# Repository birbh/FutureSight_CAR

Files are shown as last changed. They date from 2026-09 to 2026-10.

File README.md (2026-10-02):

# FutureSight_CAR:
FutureSight is an automotive dashcam built from scratch from Milk-V Duo S. It features hardware accelerated 1680p continuous loop recording with an 12c G-sensor for auto crash detection. Also I have prepared a custom 12 volt to 5 volt power converting board to handle the non sturdy vehicle(car) power.

## What makes it unique??
Unlike the commercial dashcams that lock footage behind their own apps. This project gives a person complete access and ownership of hardware and software stack. It runs a raw python on RISC-V Linux env. The hardware stack si built for extreme durability, utilizing a TPS54360DDA bulk converter and a 5.5V 4.0F supercapacitor for safe shutdown and giving time to save files before car switches off. Also it is designed to manage heat efficiently by using the large heat sync in the back panel and go-pro style mounting hinge so that it can be rotated to any angle. 

## Why i made it?
Recently my father's car got into an accident and he paid the damaged repairing cost although it wasn't his fault. So from that day i thought it would be cool if we get a dashcam(a good one). But after seeing the dashcams online the good ones were so expensive. So i thought why not make my own dashcam in home. Also i thought driving a car in those busy and chaotic roads of Kathmandu would be easier and feel confident because everything you and other person do is fully recorded and also helps us to be in discipline cause we think that this all is being recorded and we are bound to laws. 

## How to use it?
1. Mount+wire:
  Attach the dashcam module(assembled) to your car windshield using gopro compatible mount provided in 3d files of repo. Then wire 2 pin screw terminal on pcb directly to 12V power source in your car sing a cigarette lighter adapter for car.

2. Starting dashcam:
  Turn on your car. Then the system boots automatically and providing power to Milk-v-duo S. Then a background service immediately starts recording a video in 3 min. chunks.

3. Storage management:
  When the microsd card fills up, the software automatically deletes oldest normal driving footage.

4. Smart impact protection:
  If the MPU-6050 accelerometer chip detects a sudden G-force spike(triggered by eg:: hard braking, collision, car slipping etc.) , then the current video is instantly locked into `/events/` folder in sd card where it can't be overwritten. Otherwise if you press a button in the back of the dashcam it will be auto saved to `/events/` folder. Other normal recordings are saved to `/normal` folder.

## Assembly Instructions:
### 3d print enclosure:
All te 3d CAD files are provided in CAD folder of this repo. And especially 3d printable parts can be found on `/CAD/3d print/` folder in this repo. Use a high tempetrature resistant filament profile like ABS or ASA. Don't use PLA or PETG as they are not so resistant to heat and can melt on car interior temp. as it easily reaches about 70-80 °C in summer season. Also all the mounts have been pre defined in the CAD so there is no need to worry for screw fitting. 

### PCB and soldering:
Fabricate the custom matte black Kicad Pcb. Solder the SMD components first paying special attention to all components. Also before pcb printing check the 12v-5v power lines are of 1-1.5 mm width. Then solder the all the required parts to their respective footprints and places. Also snap the Milk-v-Duo S to its respective place J1 And J2 same as shown in 3d CAD model. Please ensure all the pins are arranged with the pcb otherwise it will not function. Also note that the upper black thing is completely optional because they are just pin headers that are add in 3d model. 

### Mounting:
I have provided each and every screw slots in the 3d model so that each component easily fits into the enclosure. Also dont forget to connect the camera to the milk-v duo s connector cause without camera the system is nothing. To mount camera you must take the lid side and mount the screws into it s that camera stays fit in it. 

### Flashing firmware:
Flash the official MIlk-V OS image into your SDcard. Then connect them via onboard micro sd adapter and install the required dependencies(ffmpeg,python3,py3-smbus2). Create `/mnt/sdcard/dashcam/normal/` and `/mnt/sdcard/dashcam/events/` folder/directories inside the sd card. Drop the firmware files in the root folder and enable it as a startup service. 

### Getting the data:
For now you can extract your dashcam videos by unplugging the Sd-card from the dashcam and plugging it in the sd card reader in pc,mobile or any other mountable device. And also you can directly connect your milk v type c port into your pc and access your data. But in future i plan to make a native app for the dashcam and use the inbuilt wifi antenna thing to sync the data. Also i plan to make the app fully run locally in users’ devices, protecting the privacy of the user.  

## Milk-V Duo S setup(in detail):
Once your Pcb is soldered and milk-v duo-s is mounted, follow these steps to configure dashcam:::

1. Flash the OS:
  - Download the official Milk-V Duo S Linux image from milk v [Github repo](https://github.com/milkv-duo/duo-buildroot-sdk-v2/releases)
  - then flash the image to a micros card using tools like Rufus or balenaEtcher or any other image flashing software.
  - insert the micro sd card into duo s and power it using the USB-C port(note: don't apply the car 12V power yet.)

2. Install the required drivers:
  i. For Windows users:
    Windows often fails to recognize the board automatically. You need to tell it to treat the USB connection as a network card.
    - Open Device Manager: Look under Other devices for an unknown device (often labeled Serial or RNDIS).
    - Update Driver: Right-click it, select Update driver, and choose Browse my computer for drivers.
    - Select from List: Click Let me pick from a list of available drivers on my computer.
    - Choose Network Adapters: Select Network adapters from the list, choose Microsoft as the manufacturer, and select Remote NDIS Compatible Device (or USB RNDIS Adapter).
    - Finish: Click Next and ignore any warning prompts.
    
  ii. For macos/Linux users:
    Linux and Mac usually recognize the RNDIS interface automatically, but you need to check if the network interface is active.
    - Open Terminal: Run ip a (Linux) or ifconfig (Mac).
    - Look for a new interface: You should see a new network interface (usually named something like usb0 or enX).
    
3. Setup SSH into the board:
  - Connect the Milk-V Duo S into your computer after installing required drivers.It will mount as a virtual network adapter(RNDIS).
  - Open your terminal and SSH into your default IP adress `192.168.42.1`.
  - ```bash
    ssh root@192.168.42.1
    ```
  - the default password is typically `milkv`

4. Install dependencies:
  Depending on specific os image you flashed, use the system package manager to install reqd video and python packages:
  - ```bash
    apt-get update
    sudo apt install ffmpeg
    sudo apt install python3 python3-pip
    pip3 install smbus2
    ```
5. Create the required storage directories:
  - ```bash
    mkdir -p/mnt/sdcard/dashcam/normal/
    mkdir -p/mnt/sdcard/dashcam/events/
    
6. Transfer the python script(firmware):
  From your computer use SCP(secure copy) protocol to transfer your finalized firmware firmware.py script into root folder of Milk-V Duo S:
  ```bash
scp firmware.py root@192.168.42.1:/root/
```

7. Create auto-start service when boot:
   The dashcam must boot on its own when car turns on. So use systemd to make script aut run in the bg:
   - Create the service file:
   ```bash
   vi /etc/systemd/system/dashcam.service
   ```
   - Paste the exact configuration into the file:
   ```bash
      [Unit]
      Description=Dashcam Auto recors svc
      After=systemd-modules-load.service
      
      [Service]
      Type=simple
      ExecStart=/usr/bin/python3 /root/firmware.py
      Restart=always
      RestartSec=3
      
      [Install]
      WantedBy=multi-user.target
   ```
  - Save the file and exit.

8. Enable and test:
  - Enable the service so it starts automatically on every boot.Also start manually to test it now:
    ```bash
    systemctl enable dashcam.service
    systemctl start dashcam.service
    ```
  - Verify that the camera is recording and G-sensor is polling by checking the status:
    ```bash
    systemctl status dashcam.service
    ```
  - Now at this point the usb-c cable can be disconnected and your dashcam is ready to be mounted inside the car Cigarette Lighter 12V port.... YAYYYYYY!!! les goooooooo!! 

## Future changes:
I have kept the ipex connector cable with wifi+bluetooth antenna in the pcb,BOM and CAD but that is completely optional for now as the app and the wifi setup hasnt been added in the firmware yet. In future it will be added. Also the app for the dashcam isnt functional yet and will be updated in future.

## Assets:
### CAD screenshots:
Screenshot 2026-10-02 at 6 51 13 PM
Screenshot 2026-10-02 at 6 51 52 PM
Screenshot 2026-10-02 at 6 51 38 PM
Screenshot 2026-10-02 at 6 53 03 PM
Screenshot 2026-10-02 at 6 53 45 PM

### CAD link:
[Fusion Link](https://a360.co/47AANnS)

### PCB screenshots:
Screenshot 2026-10-02 at 6 42 15 PM
Screenshot 2026-10-02 at 6 46 31 PM
Screenshot 2026-10-02 at 6 46 49 PM
Screenshot 2026-10-02 at 11 10 06 PM
Screenshot 2026-10-02 at 11 11 20 PM

### Schematic:
1. Power Control:
Screenshot 2026-10-02 at 6 48 12 PM

2. Safe shut
Screenshot 2026-10-02 at 6 49 03 PM

3. Duos_interface:
Screenshot 2026-10-02 at 6 50 06 PM

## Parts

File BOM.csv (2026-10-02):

Designator | Footprint | Quantity | Value | Component | Price | Link
C_BOOT1 | 0603 | 1 | 0.1µF | capacitor_x7r (16v or 25v) | $.11 | https://shorturl.at/1SRxo
C_COMP1 | 0603 | 1 | 3.3nF | capacitor_x7r (50v) | $.12 | https://h1.nu/1z8wH
C_IN1 | 1206 | 1 | 10µF | capacitor_x7r(50v) | $.71 | https://shorturl.at/bqJFe
C_IN2 | CP_Elec_6.3x5.8 | 1 | 47µF | capacitor_aluminium-elec(50v) | $.84 | https://h1.nu/1z8y9
C_MPU1 | 0603 | 1 | 0.1µF 10V | capacitor(10v) | $.85 | https://h1.nu/1z8z7
C_OUT1, C_OUT2 | 1206 | 2 | 22µF | capacitor_x7r(10v or 16v) | $2.25 | https://h1.nu/1z8CW
C_SUPER1 | CP_Radial_D13.0mm_P5.00mm | 1 | 5.5V 4.0F | Supercapacitor | $3.28 | https://shorturl.at/uentd
D1 | DIOM4336X265N | 1 | SMBJ24A | Unidirectional TVS Diode | $.63 | https://h1.nu/1zcSl
D2 | D_SMA_Handsoldering | 1 | 40V 3A | Schottky diode_sma | $.88 | https://h1.nu/1F28f
D_BACKUP1, D_MAIN1 | D_SMC_Handsoldering | 2 | 40V 3A | Schottky diode_smc | $3.04 | https://h1.nu/1zcYR
D_STAT1 | 0603 | 1 | LED_Small | Led-red | $.21 | https://h1.nu/1F1Za
F1 | 1812 | 1 | Polyfuse | 1812L150/24MR | $.82 | https://h1.nu/1zcVP
J1, J2 | PinSocket_2x13_P2.54mm_Vertical | 1 | Conn_02x13_Odd_Even | Milk-V-Duo-S dev board | $30.25 | https://h1.nu/1zcQ0
J3 | TerminalBlock_Phoenix_MKDS-1,5-2-5.08_1x02_P5.08mm_Horizontal | 1 | Conn_01x02 | Header to car cigratte connector | $1.16 | https://h1.nu/1F23B
L1 | L_Bourns-SRN8040_8x8.15mm | 1 | 15µH | Inductor | $.55 | https://h1.nu/1F21I
Q1 | SOT-23 | 1 | AO3401A | Mosfet | $.49 | https://h1.nu/1zcRG
R1 | 0603 | 1 | 53.6kΩ | Resistor | $.1 | https://h1.nu/1F1WV
R2 | 0603 | 1 | 10.2kΩ | Resistor | $.1 | https://h1.nu/1zcNc
R_CHARGE1 | 2512 | 1 | 10Ω 1W | Resistor | $.39 | https://h1.nu/1zcJ7
R_COMP1, R_GATE1, R_SENSE1, R_SENSE2 | 0603 | 4 | 10kΩ | Resistor | $.44 | https://h1.nu/1zcK6
R_I2C1, R_I2C2 | 0603 | 2 | 4.7kΩ | Resistor | $.20 | https://h1.nu/1zcLo
R_LED1 | 0603 | 1 | 330Ω | Resistor | $.1 | https://h1.nu/1zcLD
R_RT1 | 0603 | 1 | 162kΩ | Resistor | $.1 | https://h1.nu/1zcNt
SW1 | SW_SPST_B3S-1000 | 1 | SW_Push | Push Button Switch(with cap) | $3 | https://shorturl.at/Gz5NX
U1 | TI_SO-PowerPAD-8_ThermalVias | 1 | TPS54360DDA | Voltage regulator | $6.47 | https://shorturl.at/17ESy
U_MPU1 | InvenSense_QFN-24_4x4mm_P0.5mm | 1 | MPU-6050 | Accelererometer chip | $20.23 | https://shorturl.at/e3anJ
 |  | 1 | IPEX1 Connector | Bluetooth/WiFi Dual Bands Antenna | $6.99 | https://h1.nu/1F2bw
 |  | 1 | 12V | Car-cigarrete-adapter | $6.99 | https://h1.nu/1F2hT
 |  | 1 | Night Vision 130 | Camera module OV5640 | $8.97 | https://shorturl.at/GuyvN
 |  | 1 | 14mm diameter | Camera Lens protector | $0.81 | https://shorturl.at/D2TVY
Total |  |  |  |  | $101.08

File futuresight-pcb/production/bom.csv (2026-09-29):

Designator | Footprint | Quantity | Value | LCSC Part #
C_BOOT1 | 0603 | 1 | 0.1µF
C_COMP1 | 0603 | 1 | 3.3nF
C_IN1 | 1206 | 1 | 10µF
C_IN2 | CP_Elec_6.3x5.8 | 1 | 47µF
C_MPU1 | 0603 | 1 | 0.1µF 10V
C_OUT1, C_OUT2 | 1206 | 2 | 22µF
C_SUPER1 | CP_Radial_D13.0mm_P5.00mm | 1 | 5.5V 4.0F
D1 | DIOM4336X265N | 1 | SMBJ24A
D2 | D_SMA_Handsoldering | 1 | 40V 3A
D_BACKUP1, D_MAIN1 | D_SMC_Handsoldering | 2 | 40V 3A
D_STAT1 | 0603 | 1 | LED_Small
F1 | 1812 | 1 | Polyfuse
J1, J2 | PinSocket_2x13_P2.54mm_Vertical | 2 | Conn_02x13_Odd_Even
J3 | TerminalBlock_Phoenix_MKDS-1,5-2-5.08_1x02_P5.08mm_Horizontal | 1 | Conn_01x02
L1 | L_Bourns-SRN8040_8x8.15mm | 1 | 15µH
Q1 | SOT-23 | 1 | AO3401A
R1 | 0603 | 1 | 53.6kΩ
R2 | 0603 | 1 | 10.2kΩ
R_CHARGE1 | 2512 | 1 | 10Ω 1W
R_COMP1, R_GATE1, R_SENSE1, R_SENSE2 | 0603 | 4 | 10kΩ
R_I2C1, R_I2C2 | 0603 | 2 | 4.7kΩ
R_LED1 | 0603 | 1 | 330Ω
R_RT1 | 0603 | 1 | 162kΩ
SW1 | SW_SPST_B3S-1000 | 1 | SW_Push
U1 | TI_SO-PowerPAD-8_ThermalVias | 1 | TPS54360DDA
U_MPU1 | InvenSense_QFN-24_4x4mm_P0.5mm | 1 | MPU-6050

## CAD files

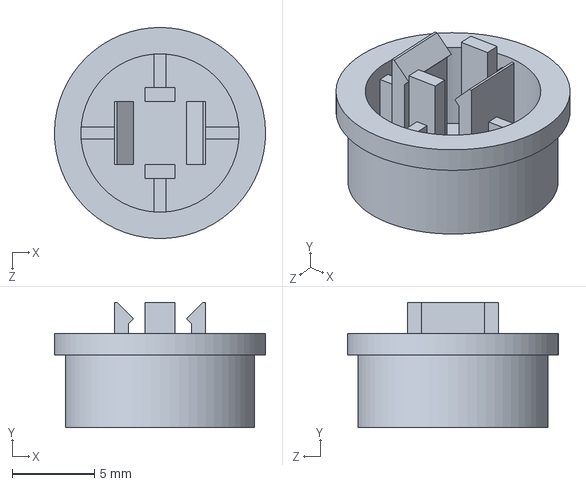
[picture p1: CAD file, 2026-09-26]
CAD/parts/Tactile Button Caps for B3F-4055 12X12X7.3MM.SLDPRT
12.8 x 7.60 x 12.8 mm

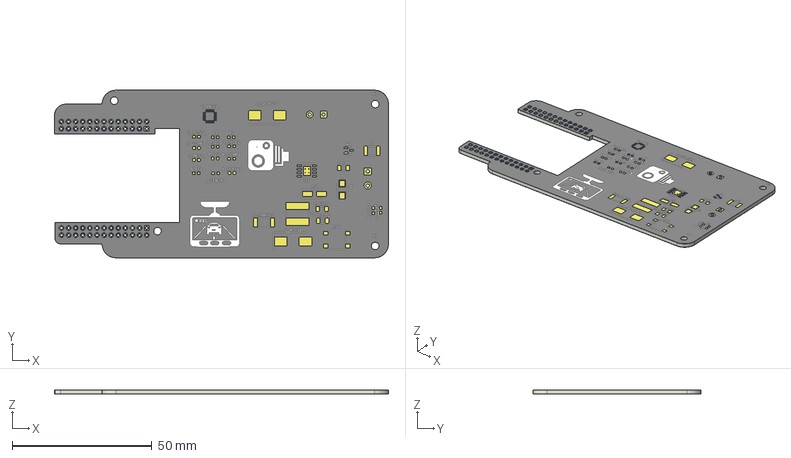
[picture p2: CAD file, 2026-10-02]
CAD/pcb/pcb_no_components.step
119.5 x 60.0 x 1.66 mm
futuresight-unsaved-export-hXkzsr_copper
futuresight-unsaved-export-hXkzsr_pad
futuresight-unsaved-export-hXkzsr_via
futuresight-unsaved-export-hXkzsr_silkscreen x 2
futuresight-unsaved-export-hXkzsr_soldermask x 2
futuresight-unsaved-export-hXkzsr_PCB

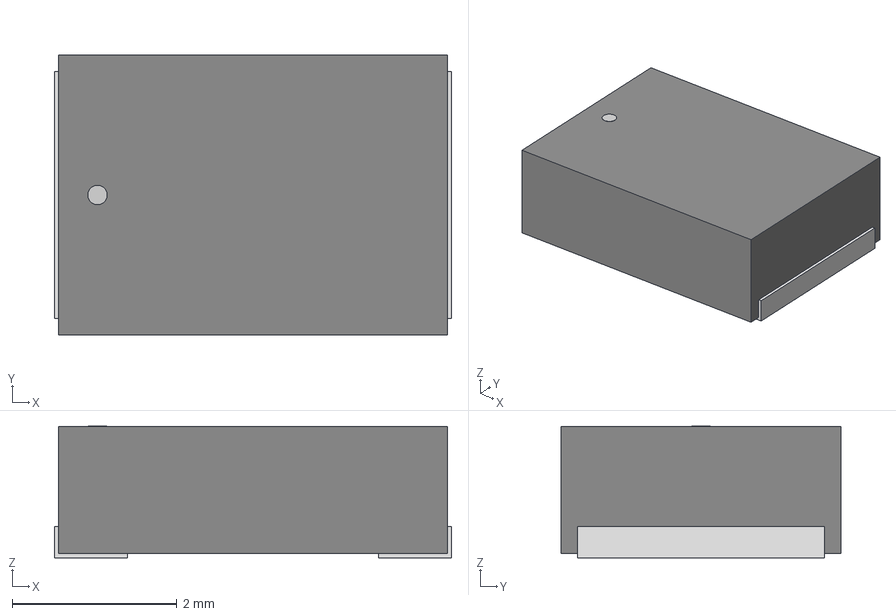
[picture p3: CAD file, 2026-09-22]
futuresight-pcb/fuse/FUSE_MF-MSMF150_BRN.step
4.83 x 3.40 x 1.60 mm

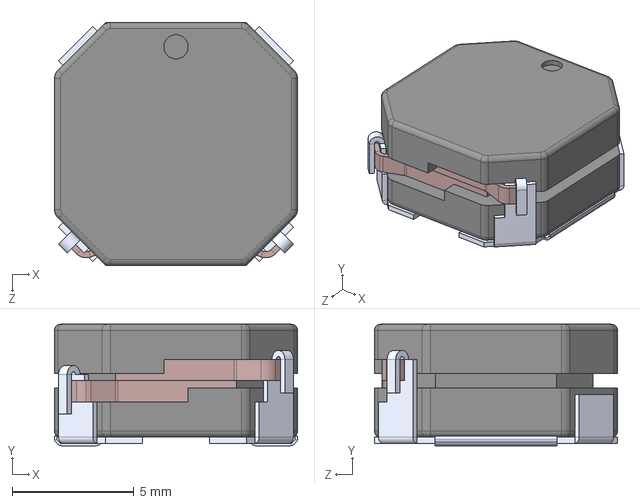
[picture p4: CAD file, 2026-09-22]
futuresight-pcb/inductor/1274AS-H-150M=P3.STEP
10.0 x 5.00 x 10.0 mm

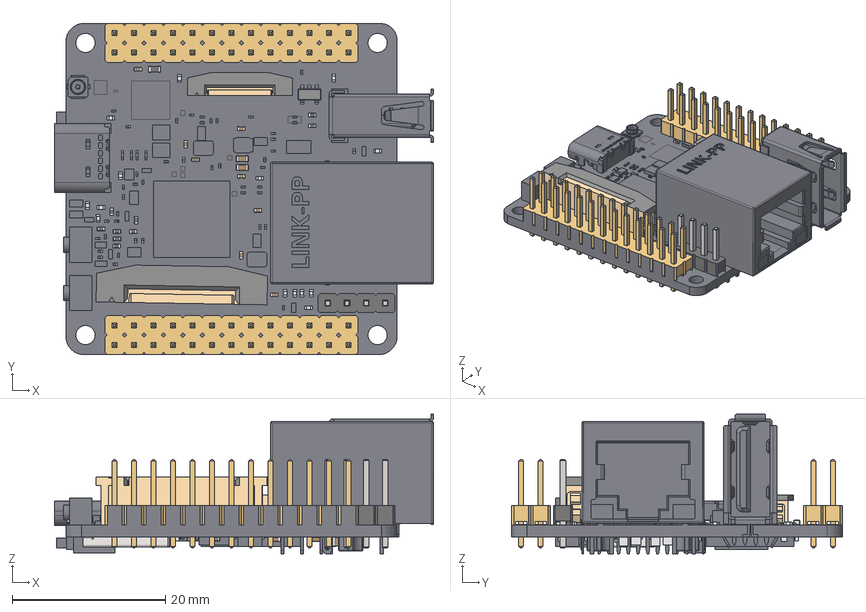
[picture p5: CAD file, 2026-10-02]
futuresight-pcb/milk-v/duo_s_pcb_3d.step
49.4 x 43.2 x 18.2 mm

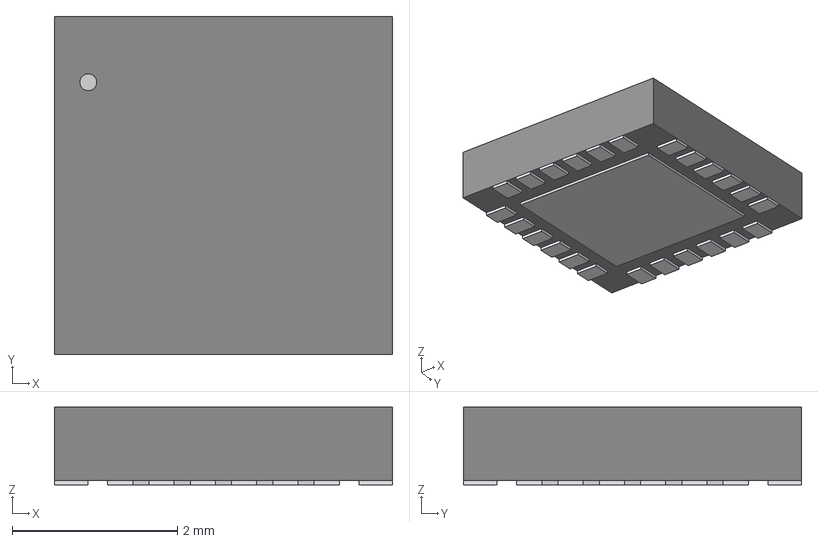
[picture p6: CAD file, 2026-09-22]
futuresight-pcb/mpu6050/QFN24_4X4X0P9-0P5_TDK.step
4.09 x 4.09 x 0.942 mm

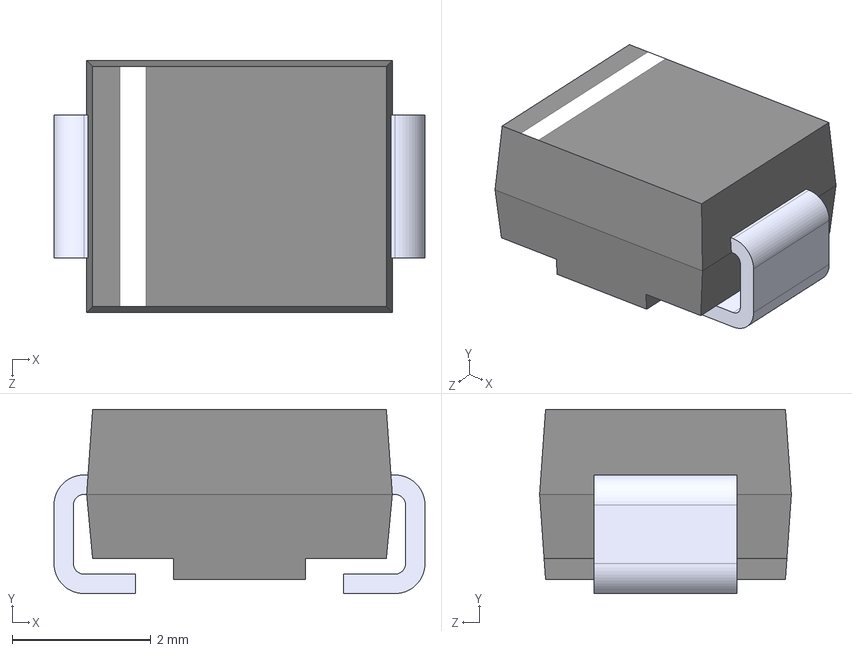
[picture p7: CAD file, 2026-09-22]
futuresight-pcb/SMBJ24A/SMBJ24A.step
5.34 x 2.65 x 3.62 mm

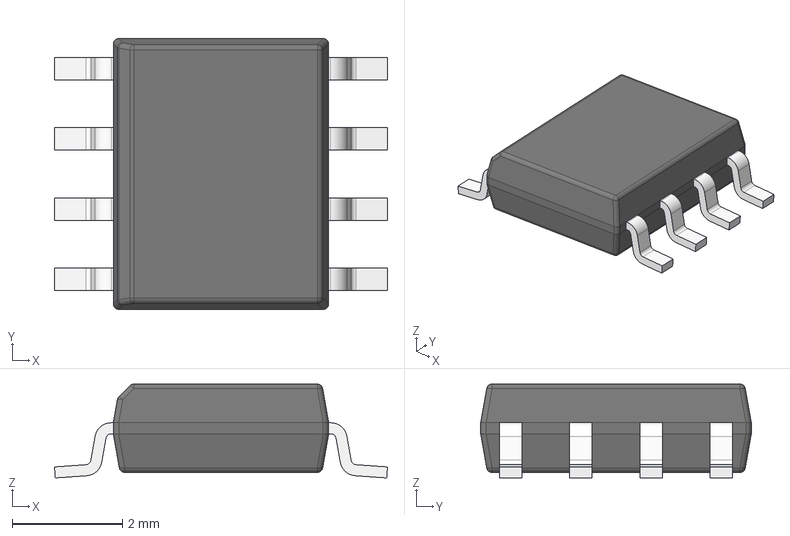
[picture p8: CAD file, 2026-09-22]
futuresight-pcb/TPS54360DDA/DDA0008E.stp
6.03 x 4.90 x 1.70 mm
BODY-SO
LEAD-SO x 8
THERMALPAD-SO

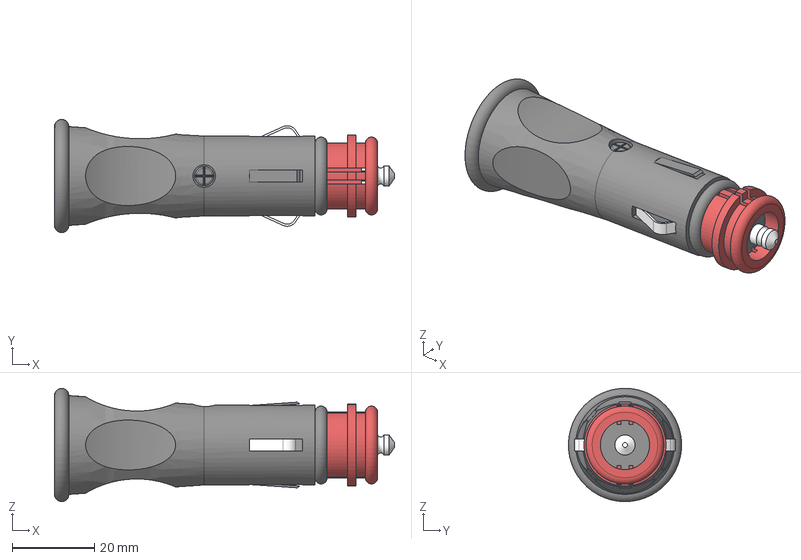
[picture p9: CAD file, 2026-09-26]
CAD/parts/12V Male Car Cigarette Lighter Socket Plug Connector.stp
82.9 x 27.6 x 27.6 mm

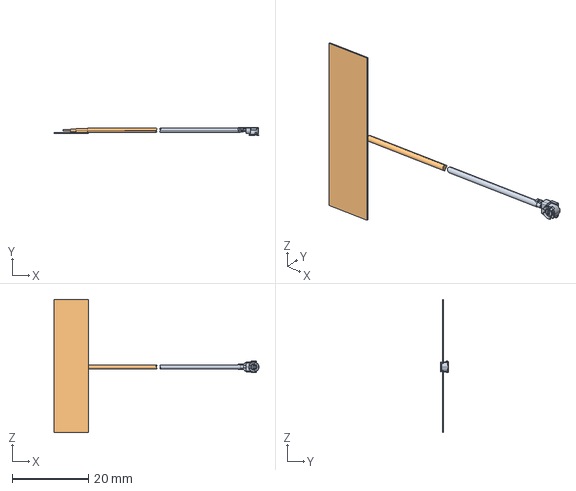
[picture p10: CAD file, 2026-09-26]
CAD/parts/1461530100.stp
53.6 x 2.15 x 34.9 mm

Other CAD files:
CAD/3d print/GoPro+Peak+Design+Clip+Compatible+Plate.f3d
CAD/3d print/GoPro+vite-head.f3d
CAD/3d print/base.f3d
CAD/3d print/lid.f3d
CAD/parts/1274AS-H-220M=P3.f3d
CAD/parts/92314A652_18-8 Stainless Steel Hex Head Screws.f3d
CAD/parts/CP_Elec_63x58.f3d
CAD/parts/CP_Radial_D130mm_P500mm.f3d
CAD/parts/C_0805_2012Metric.f3d
CAD/parts/C_1206_3216Metric.f3d
CAD/parts/D_SMA.f3d
CAD/parts/D_SMC.f3d
CAD/parts/GoPro+Peak+Design+Clip+Compatible+Plate.f3d
CAD/parts/GoPro+vite-head.f3d
CAD/parts/PinSocket_2x13_P2.54mm_Vertical.f3d
CAD/parts/R_0603_1608Metric.f3d
CAD/parts/R_2512_6332Metric.f3d
CAD/parts/SOT-23.f3d
CAD/parts/SW_SPST_B3S-1000.f3d
CAD/parts/TPS54360DDA.f3d
CAD/parts/TerminalBlock_Phoenix_MKDS-1,5-2-5.08_1x02_P5.08mm_Horizontal.f3d
CAD/parts/base.f3d
CAD/parts/lens-filter.f3d
CAD/parts/lid.f3d
CAD/parts/milk-v-duo-s.f3d
CAD/parts/mpu-6050.f3d
CAD/parts/part.f3d
CAD/parts/smbj24a.f3d

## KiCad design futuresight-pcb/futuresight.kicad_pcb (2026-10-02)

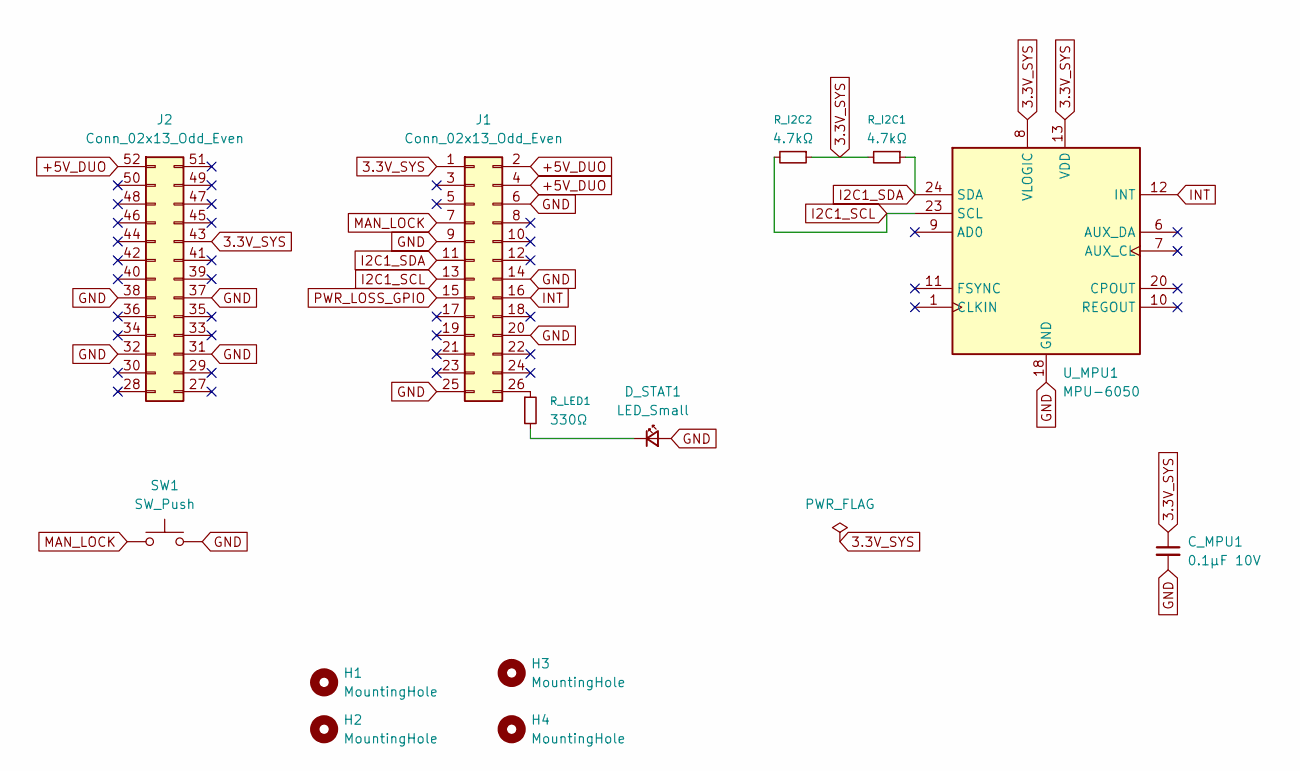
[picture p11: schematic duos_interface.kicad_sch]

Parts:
C_MPU1: 0.1µF 10V; C_0603_1608Metric_Pad1.08x0.95mm_HandSolder
D_STAT1: LED_Small; LED_0603_1608Metric_Pad1.05x0.95mm_HandSolder
H1, H2, H3, H4: MountingHole; MountingHole_2.7mm_M2.5
J1, J2: Conn_02x13_Odd_Even; PinSocket_2x13_P2.54mm_Vertical
R_I2C1, R_I2C2: 4.7kΩ; R_0603_1608Metric_Pad0.98x0.95mm_HandSolder
R_LED1: 330Ω; R_0603_1608Metric_Pad0.98x0.95mm_HandSolder
SW1: SW_Push; SW_SPST_B3S-1000
U_MPU1: MPU-6050; InvenSense_QFN-24_4x4mm_P0.5mm

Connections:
3.3V_SYS: C_MPU1.1, J1.1, J2.43, R_I2C1.2, R_I2C2.1, U_MPU1.8 (VLOGIC), U_MPU1.13 (VDD)
+5V_DUO: J1.2, J1.4, J2.52; also elsewhere on the board
GND: C_MPU1.2, D_STAT1.2 (A), J1.6, J1.9, J1.14, J1.20, J1.25, J2.31, J2.32, J2.37, J2.38, SW1.2, U_MPU1.18 (GND); also elsewhere on the board
I2C1_SCL: J1.13, R_I2C2.2, U_MPU1.23 (SCL)
I2C1_SDA: J1.11, R_I2C1.1, U_MPU1.24 (SDA)
INT: J1.16, U_MPU1.12 (INT)
MAN_LOCK: J1.7, SW1.1
unnamed: D_STAT1.1 (K), R_LED1.2
unnamed: J1.26, R_LED1.1
PWR_LOSS_GPIO: J1.15; also elsewhere on the board

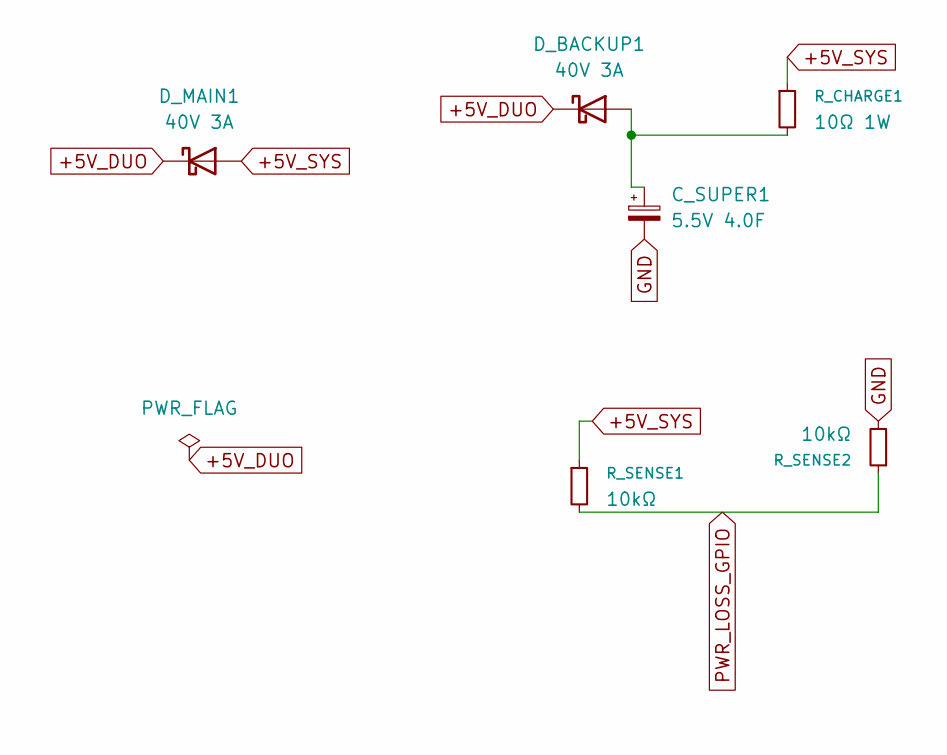
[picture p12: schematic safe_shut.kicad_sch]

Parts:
C_SUPER1: 5.5V 4.0F; CP_Radial_D24.0mm_P10.00mm_SnapIn
D_BACKUP1: 40V 3A; D_SMC_Handsoldering
D_MAIN1: 40V 3A; D_SMC_Handsoldering
R_CHARGE1: 10Ω 1W; R_2512_6332Metric_Pad1.40x3.35mm_HandSolder
R_SENSE1, R_SENSE2: 10kΩ; R_0603_1608Metric_Pad0.98x0.95mm_HandSolder

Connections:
+5V_DUO: D_BACKUP1.1 (K), D_MAIN1.1 (K); also elsewhere on the board
+5V_SYS: D_MAIN1.2 (A), R_CHARGE1.1, R_SENSE1.1; also elsewhere on the board
GND: C_SUPER1.2, R_SENSE2.2; also elsewhere on the board
unnamed: C_SUPER1.1, D_BACKUP1.2 (A), R_CHARGE1.2
PWR_LOSS_GPIO: R_SENSE1.2, R_SENSE2.1; also elsewhere on the board

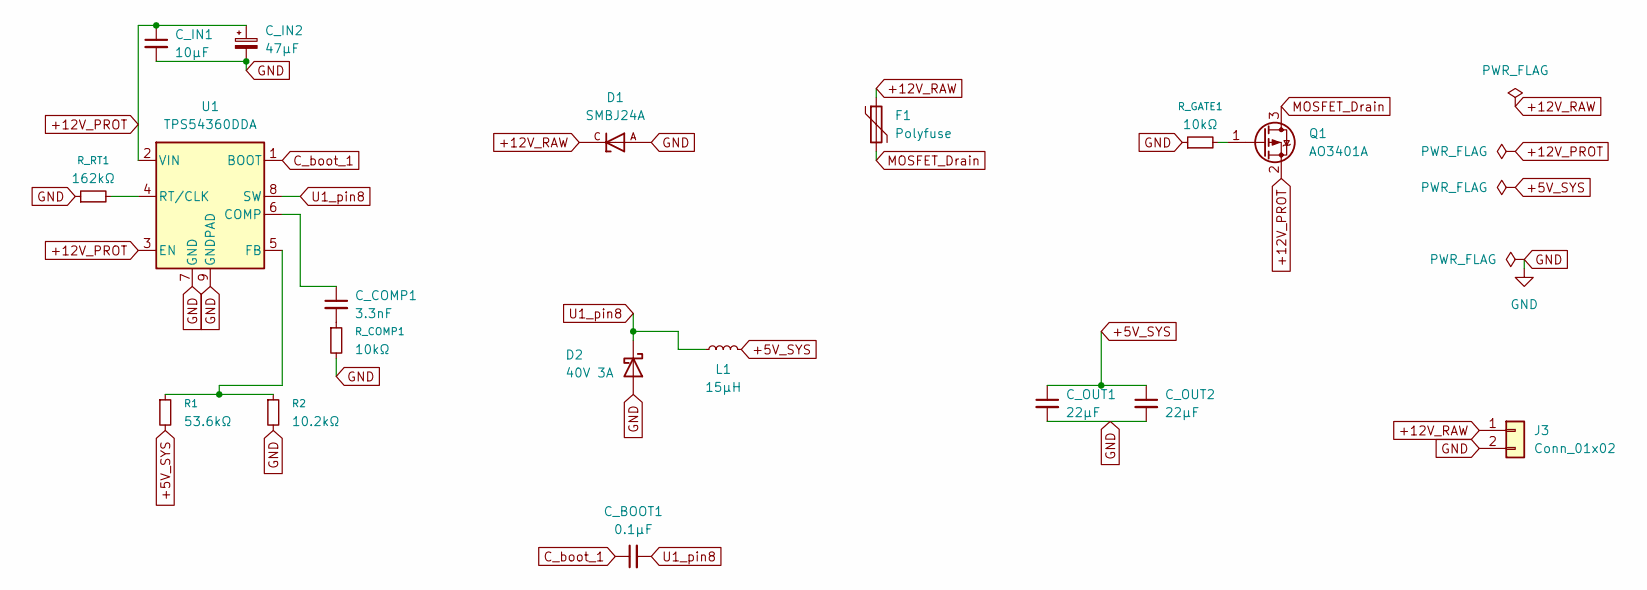
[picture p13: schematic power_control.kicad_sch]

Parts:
C_BOOT1: 0.1µF; C_0603_1608Metric_Pad1.08x0.95mm_HandSolder
C_COMP1: 3.3nF; C_0603_1608Metric_Pad1.08x0.95mm_HandSolder
C_IN1: 10µF; C_1206_3216Metric_Pad1.33x1.80mm_HandSolder
C_IN2: 47µF; CP_Elec_6.3x5.8
C_OUT1, C_OUT2: 22µF; C_1206_3216Metric_Pad1.33x1.80mm_HandSolder
D1: SMBJ24A; DIOM4336X265N; PARTREV F2102
D2: 40V 3A; D_SMA_Handsoldering
F1: Polyfuse; Fuse_1812_4532Metric_Pad1.30x3.40mm_HandSolder
J3: Conn_01x02; TerminalBlock_Phoenix_MKDS-1,5-2-5.08_1x02_P5.08mm_Horizont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
L1: 15µH; L_Bourns-SRN8040_8x8.15mm
Q1: AO3401A; SOT-23
R1: 53.6kΩ; R_0603_1608Metric_Pad0.98x0.95mm_HandSolder
R2: 10.2kΩ; R_0603_1608Metric_Pad0.98x0.95mm_HandSolder
R_COMP1: 10kΩ; R_0603_1608Metric_Pad0.98x0.95mm_HandSolder
R_GATE1: 10kΩ; R_0603_1608Metric_Pad0.98x0.95mm_HandSolder
R_RT1: 162kΩ; R_0603_1608Metric_Pad0.98x0.95mm_HandSolder
U1: TPS54360DDA; TI_SO-PowerPAD-8_ThermalVias

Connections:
+5V_SYS: C_OUT1.1, C_OUT2.1, L1.2, R1.2; also elsewhere on the board
+12V_PROT: C_IN1.1, C_IN2.1, Q1.2 (S), U1.2 (VIN), U1.3 (EN)
+12V_RAW: D1.C, F1.1, J3.1
C_boot_1: C_BOOT1.1, U1.1 (BOOT)
GND: C_IN1.2, C_IN2.2, C_OUT1.2, C_OUT2.2, D1.A, D2.2 (A), J3.2, R2.2, R_COMP1.2, R_GATE1.1, R_RT1.1, U1.7 (GND), U1.9 (GNDPAD); also elsewhere on the board
MOSFET_Drain: F1.2, Q1.3 (D)
unnamed: C_COMP1.2, R_COMP1.1
unnamed: Q1.1 (G), R_GATE1.2
unnamed: C_COMP1.1, U1.6 (COMP)
unnamed: R1.1, R2.1, U1.5 (FB)
unnamed: R_RT1.2, U1.4 (RT/CLK)
U1_pin8: C_BOOT1.2, D2.1 (K), L1.1, U1.8 (SW)

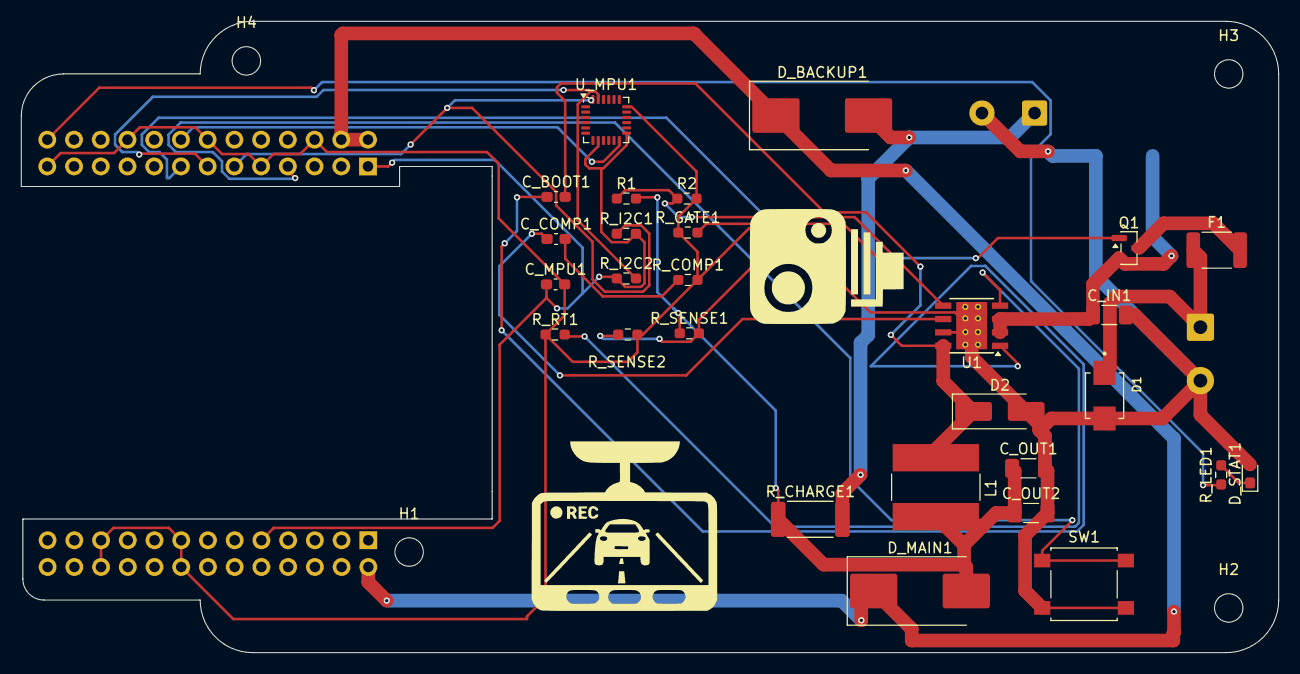
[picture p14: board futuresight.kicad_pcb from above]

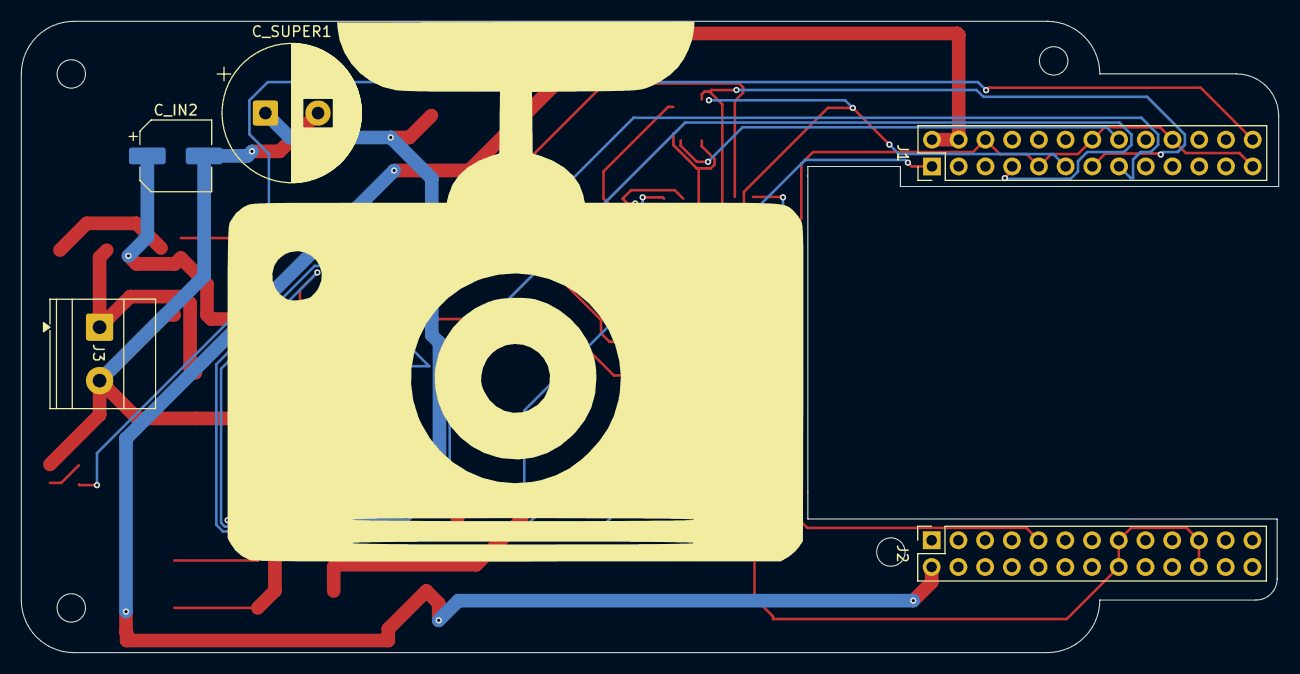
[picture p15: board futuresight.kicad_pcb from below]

Board: 2 copper layers, 119.5 x 60.0 mm, 37 parts (5 on the bottom side), 22 nets.

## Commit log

2026-09-26 update pcb and CAD files
    [1274AS-H-150M=P3.STEP, 1274AS-H-220M=P3.f3d, 12V Male Car Cigarette Lighter Socket Plug Connector.stp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]
2026-09-29 updated -- pcb CAD firmware
    [futuresight.kicad_pcb, pcb_no_components.step]
2026-09-29 update ini. bom +pcb. change
    [BOM.csv, bom.csv, futuresight.kicad_pcb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]
2026-09-30 update pcb path
    [1274AS-H-150M=P3.STEP, BOM.csv, DDA0008E.stp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]
2026-10-01 Update README with project details and instructions
    Added detailed project description, usage instructions, assembly instructions, and unique features of the FutureSight dashcam.
2026-10-02 Enhance README with firmware and data extraction details
    Updated the README to include detailed instructions for flashing firmware, extracting dashcam videos, and future plans for app development. Added CAD and PCB screenshots along with links.
2026-10-02 Expand README with Milk-V Duo S setup instructions
    Added detailed setup instructions for the Milk-V Duo S dashcam, including OS flashing, driver installation, SSH setup, dependency installation, and service configuration.
2026-10-02 Add new PCB screenshots to README
    Added two new PCB screenshots to the README.
2026-10-02 updated BOM,PCB, some 3d files
    [BOM.csv, duo_s_pcb_3d.step, futuresight.kicad_pcb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]
